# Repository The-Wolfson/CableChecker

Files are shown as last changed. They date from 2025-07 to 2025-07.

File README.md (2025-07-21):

# Cable Checker
A handheld device to check XLR3 cables faster.

## Basic Operation
This device has 3 testing modes:
- input (tests incoming signal)
- output (tests outgoing signal)
- both (tests both incoming and outgoing signals)

These are controlled by the slide switch ion the side.

To start a test, hold the rotary encoder down for 3 seconds. The test will run for 5 seconds, afterwards the LEDs will show the results and input levels.

There is also a headphone jack, the knob can be used for volume.

When in output mode, the knob is used for volume.

## BOM

| Item | Model | Qty | Price (USD) | Shipping | Link |
|-|-|-|-|-|-|
| Audio Codec | ES8388 | 1 | $2.51 | $9.34 USD | [Link](https://lcsc.com/product-detail/ADCs-DACs-Special-Purpose_Everest-semi-Everest-Semiconductor-ES8388_C365736.html) |
| Audio Transformer | HR610660 | 2 | $1.03 | '' | [Link](https://lcsc.com/product-detail/Audio-Transformers_HANRUN-Zhongshan-HanRun-Elec-HR610660_C48357.html) |
| XLR3 Male | NC3MAAH | 1 | $1.57 | '' | [Link](https://lcsc.com/product-detail/XLR-Cannon-Connectors_Neutrik-NC3MAAH_C368463.html) |
| XLR3 Female | NC3FAAH | 1 | $1.43 | '' | [Link](https://lcsc.com/product-detail/XLR-Cannon-Connectors_Neutrik-NC3FAAH_C368521.html) |
| Audio Jack | PJ-306M | 1 | $1.14 | '' | [Link](https://lcsc.com/product-detail/Audio-Connectors_HOOYA-PJ-306M_C2939172.html) |
| Rotary Encoder w/ Button | PEC11R-4220F-S0024 | 1 | $2.80  | '' | [Link](https://lcsc.com/product-detail/Rotary-Encoders_BOURNS-PEC11R-4220F-S0024_C143797.html) |
| Slide Switch (SP3T) | SK13D07VG5 | 1 | $0.66 | '' | [Link](https://lcsc.com/product-detail/Slide-Switches_SHOU-HAN-SK13D07VG5_C393948.html) |
| Microcontroller | ESP32-S3-Zero | 1 | $6.06 | Free | [Link](https://core-electronics.com.au/esp32-s3-mini-development-board-retired.html) |
| LED Bar Graph | WS2812B | 1 | $3.19 | '' | [Link](https://core-electronics.com.au/glowbit-stick-1x8.html) |
| Encoder Knob | ADA5093 | 1 | $1.17 | '' | [Link](https://core-electronics.com.au/slim-rubber-rotary-encoder-knob-11-5mm-x-14-5mm-d-shaft.html) |
| PCB (JLCPCB) | - | 5 | $2 | $16.59 AUD | [Link](https://jlcpcb.com) |
| PCB Assembly (for ES8388) | - | 2 | $15.40 | '' | [Link](https://jlcpcb.com) |
| Case (Print Legion) | - | 1 | $0 | $5 AUD | [Link](https://printlegion.hackclub.com) |

**AUD Total:** $98.46

**USD Total:** $62.35

## Background
I run sound at my school, and we have a legacy system, set up who knows how many years ago. As part of that, there are lots of XLR3 cables lying around that nobody knows if they work, or not.

The solution to my problem, a small portable device that tests if the XLR cable is functioning properly. THis exists... for around $350 AUD. 

So, when I heard about Hackclub's *Highway* YSWS, my mind immediately jumped to this.
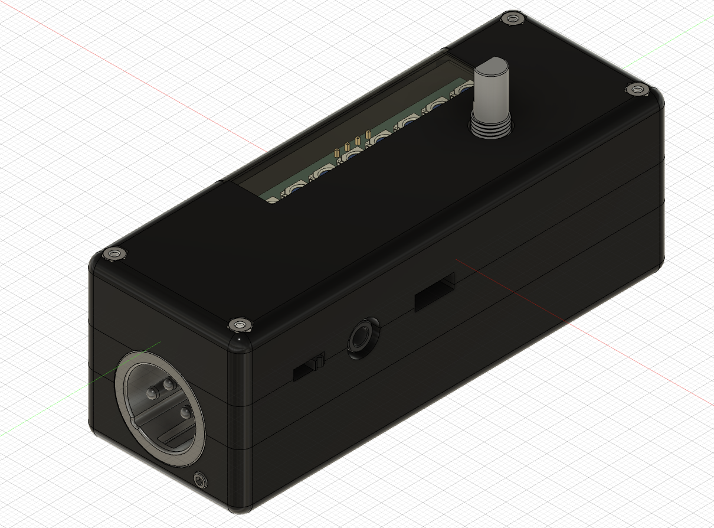
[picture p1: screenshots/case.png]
Case

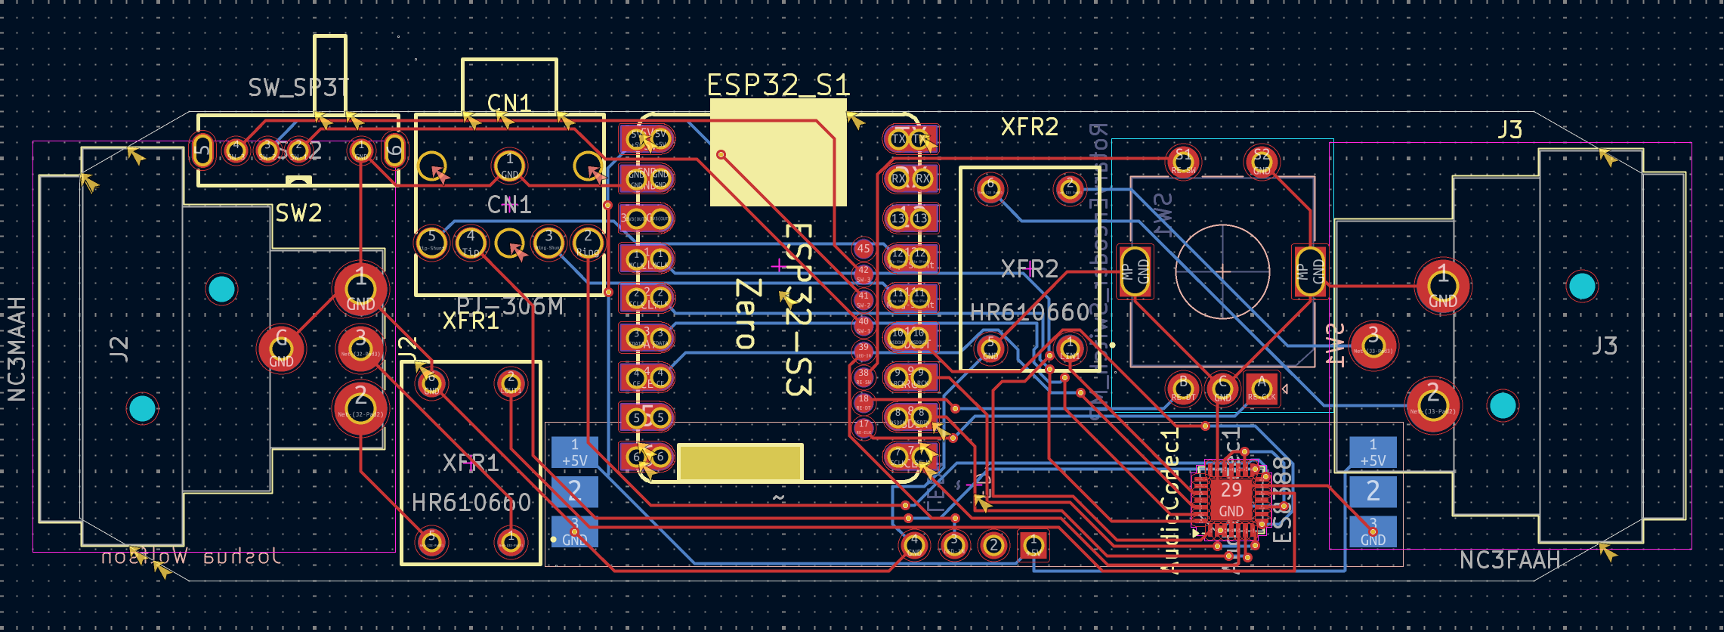
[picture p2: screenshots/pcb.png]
PCB

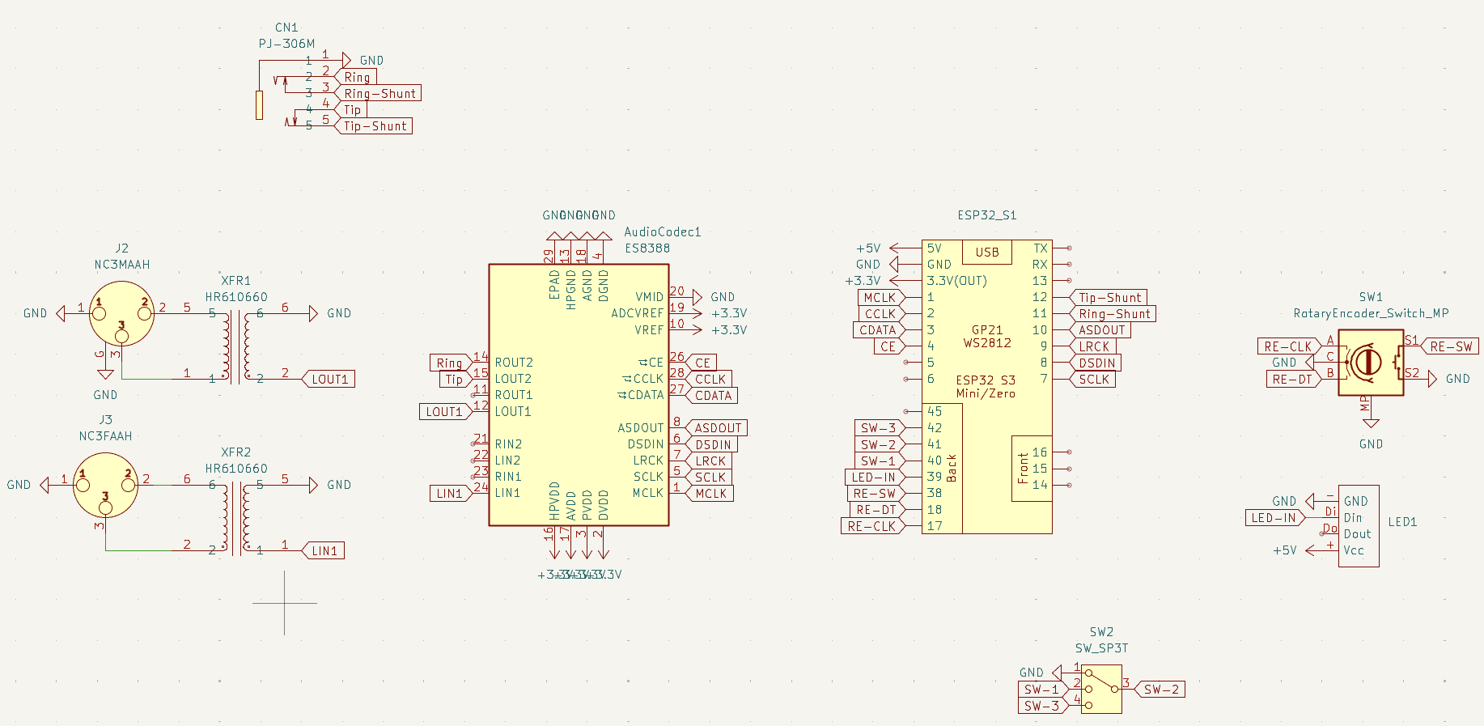
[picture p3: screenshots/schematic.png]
Schematic

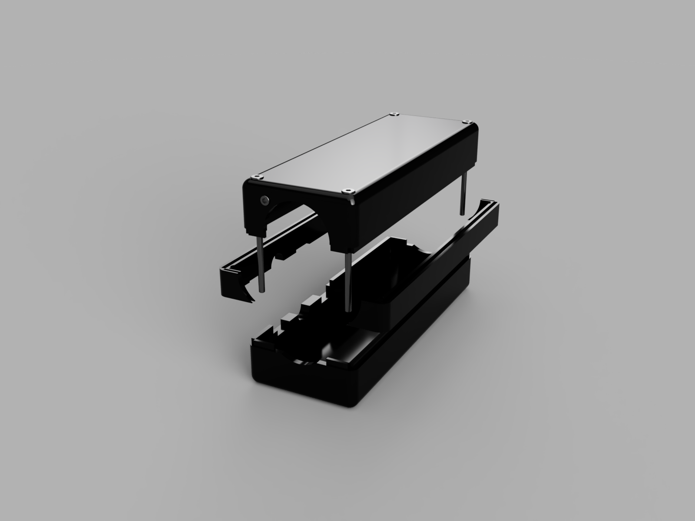
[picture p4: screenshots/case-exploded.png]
Case Assembly


## Additional Details
- I'm using a 14mmx55mmx2mm transparent acrylic sheet instead of the window print.

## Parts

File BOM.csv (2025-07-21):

Part | SKU | Model | Quantity | Price (AUD) | Price (USD) | Shipping (AUD) | Shipping (USD) | Total (AUD) | Total (USD) | Link
Audio Transformer | C48357 | HR610660 | 2 | $- | $2.51 | $- | $9.34 | $18.20 | $11.85 | https://lcsc.com/product-detail/Audio-Transformers_HANRUN-Zhongshan-HanRun-Elec-HR610660_C48357.html
Audio Codec | C365736 | ES8388 | 1 | $- | $1.03 | $- | ' | $1.58 | $1.03 | https://lcsc.com/product-detail/ADCs-DACs-Special-Purpose_Everest-semi-Everest-Semiconductor-ES8388_C365736.html
XLR3 Male | C368463 | NC3MAAH | 1 | $- | $1.57 | $- | ' | $2.41 | $1.57 | https://lcsc.com/product-detail/XLR-Cannon-Connectors_Neutrik-NC3MAAH_C368463.html
XLR3 Female | C368521 | NC3FAAH | 1 | $- | $1.43 | $- | ' | $2.20 | $1.43 | https://lcsc.com/product-detail/XLR-Cannon-Connectors_Neutrik-NC3FAAH_C368521.html
Rotary Encoder w/ Button | C143797 | PEC11R-4220F-S0024 | 1 | $- | $2.80 | $- | ' | $4.30 | $2.80 | https://lcsc.com/product-detail/Rotary-Encoders_BOURNS-PEC11R-4220F-S0024_C143797.html
Audio Jack | C2939172 | PJ-306M | 5 | $- | $1.14 | $- | ' | $1.75 | $1.14 | https://lcsc.com/product-detail/Audio-Connectors_HOOYA-PJ-306M_C2939172.html
Slide Switch (SP3T) | C393948 | SK13D07VG5 | 20 | $- | $0.66 | $- | ' | $1.01 | $0.66 | https://lcsc.com/product-detail/Slide-Switches_SHOU-HAN-SK13D07VG5_C393948.html
Microcontroller | WS-25081 | ESP32-S3-Zero | 1 | $9.30 | $- | $- | $- | $9.30 | $6.05 | https://core-electronics.com.au/esp32-s3-mini-development-board-retired.html
Encoder Knob | ADA5093 | - | 1 | $1.80 | $- | $- | $- | $1.80 | $1.17 | https://core-electronics.com.au/slim-rubber-rotary-encoder-knob-11-5mm-x-14-5mm-d-shaft.html
LED Bar Graph | CE08035 | WS2812B | 1 | $4.90 | $- | $- | ' | $4.90 | $3.19 | https://core-electronics.com.au/glowbit-stick-1x8.html
M2x38 |  |  | 4 |  |  |  |  | $- | $-
M1.6x12 |  |  | 2 |  |  |  |  | $- | $-
PCB | JLCPCB |  | 5 | $3.07 | $- | $16.59 | $- | $19.66 | $12.80 | https://jlcpcb.com
PCB Assembly (for ES8388) | JLCPCB |  | 2 | $23.67 |  |  |  | $23.67 | $15.41 | https://jlcpcb.com
Case | Printing Legion |  |  | $- | $- | $5.00 | $- | $7.68 | $3.25 | https://printlegion.hackclub.com
Total |  |  |  |  |  |  |  | $98.46 | $62.35

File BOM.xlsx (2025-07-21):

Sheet: BOM
Part | SKU | Model | Quantity | Price (AUD) | Price (USD) | Shipping (AUD) | Shipping (USD) | Total (AUD) | Total (USD) | Link
Audio Transformer | C48357 | HR610660 | 2 | $0.00 | $2.51 | $0.00 | $9.34 | $18.20 | $11.85 | https://lcsc.com/product-detail/Audio-Transformers_HANRUN-Zhongshan-HanRun-Elec-HR610660_C48357.html
Audio Codec | C365736 | ES8388 | 1 | $0.00 | $1.03 | $0.00 | ' | $1.58 | $1.03 | https://lcsc.com/product-detail/ADCs-DACs-Special-Purpose_Everest-semi-Everest-Semiconductor-ES8388_C365736.html
XLR3 Male | C368463 | NC3MAAH | 1 | $0.00 | $1.57 | $0.00 | ' | $2.41 | $1.57 | https://lcsc.com/product-detail/XLR-Cannon-Connectors_Neutrik-NC3MAAH_C368463.html
XLR3 Female | C368521 | NC3FAAH | 1 | $0.00 | $1.43 | $0.00 | ' | $2.20 | $1.43 | https://lcsc.com/product-detail/XLR-Cannon-Connectors_Neutrik-NC3FAAH_C368521.html
Rotary Encoder w/ Button | C143797 | PEC11R-4220F-S0024 | 1 | $0.00 | $2.80 | $0.00 | ' | $4.30 | $2.80 | https://lcsc.com/product-detail/Rotary-Encoders_BOURNS-PEC11R-4220F-S0024_C143797.html
Audio Jack | C2939172 | PJ-306M | 5 | $0.00 | $1.14 | $0.00 | ' | $1.75 | $1.14 | https://lcsc.com/product-detail/Audio-Connectors_HOOYA-PJ-306M_C2939172.html
Slide Switch (SP3T) | C393948 | SK13D07VG5 | 20 | $0.00 | $0.66 | $0.00 | ' | $1.01 | $0.66 | https://lcsc.com/product-detail/Slide-Switches_SHOU-HAN-SK13D07VG5_C393948.html
Microcontroller | WS-25081 | ESP32-S3-Zero | 1 | $9.30 | $0.00 | $0.00 | $0.00 | $9.30 | $6.05 | https://core-electronics.com.au/esp32-s3-mini-development-board-retired.html
Encoder Knob | ADA5093 | - | 1 | $1.80 | $0.00 | $0.00 | $0.00 | $1.80 | $1.17 | https://core-electronics.com.au/slim-rubber-rotary-encoder-knob-11-5mm-x-14-5mm-d-shaft.html
LED Bar Graph | CE08035 | WS2812B | 1 | $4.90 | $0.00 | $0.00 | ' | $4.90 | $3.19 | https://core-electronics.com.au/glowbit-stick-1x8.html
M2x38 |  |  | 4 |  |  |  |  | $0.00 | $0.00
M1.6x12 |  |  | 2 |  |  |  |  | $0.00 | $0.00
PCB | JLCPCB |  | 5 | $3.07 | $0.00 | $16.59 | $0.00 | $19.66 | $12.80 | https://jlcpcb.com
PCB Assembly (for ES8388) | JLCPCB |  | 2 | $23.67 |  |  |  | $23.67 | $15.41 | https://jlcpcb.com
Case | Printing Legion |  |  | $0.00 | $0.00 | $5.00 | $0.00 | $7.68 | $3.25 | https://printlegion.hackclub.com
Total |  |  |  |  |  |  |  | $98.46 | $62.35

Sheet: Exchange
Currency Pair | Price | Last trade time
#VALUE! | $1.54 | 2025-07-21 09:34
#VALUE! | $0.65 | 2025-07-21 09:34

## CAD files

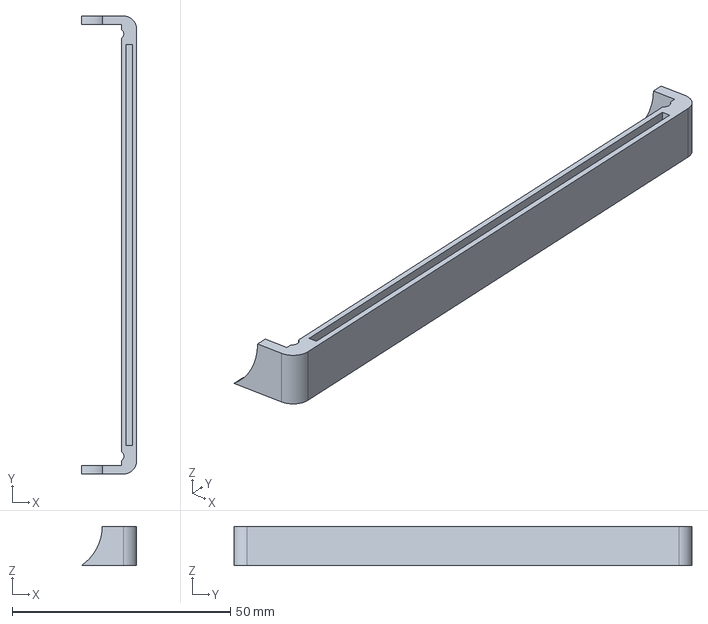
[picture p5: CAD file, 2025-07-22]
production/case/middle (1).step
12.7 x 105.0 x 9.00 mm

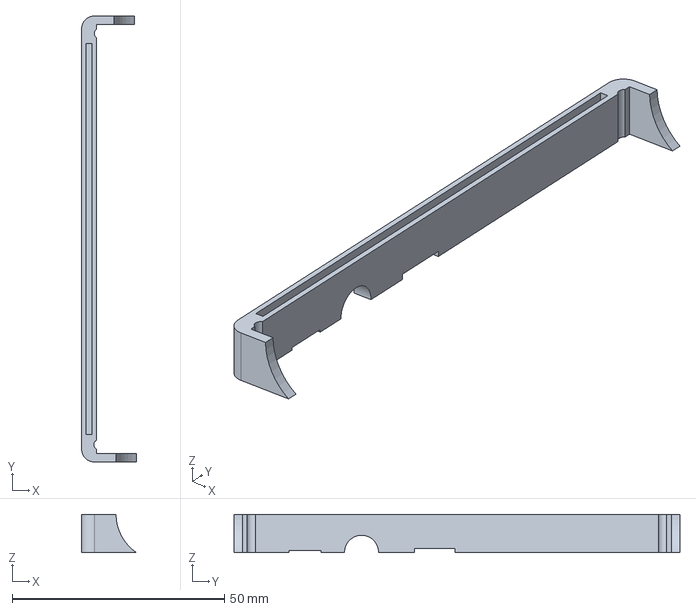
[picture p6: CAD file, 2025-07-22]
production/case/middle (2).step
12.9 x 105.0 x 9.00 mm

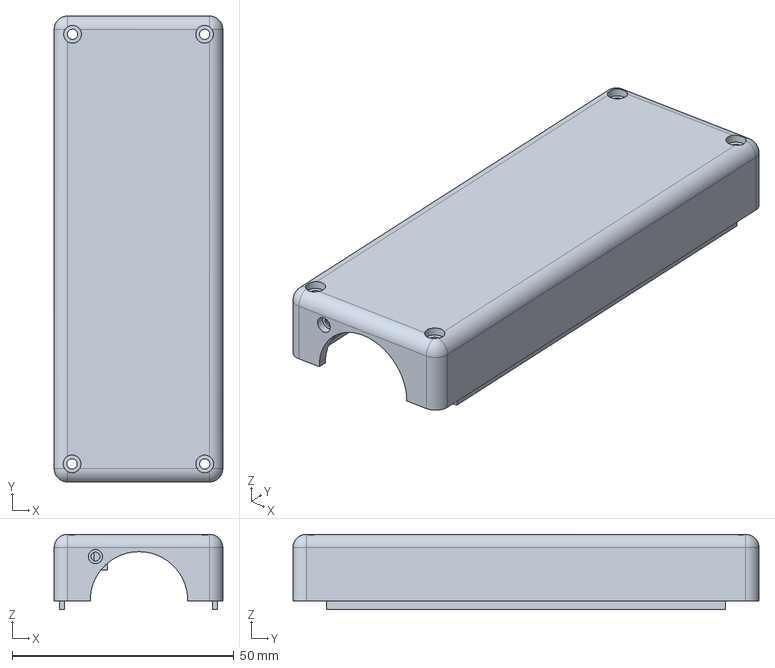
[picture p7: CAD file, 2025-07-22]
production/case/top.step
38.0 x 105.0 x 17.0 mm

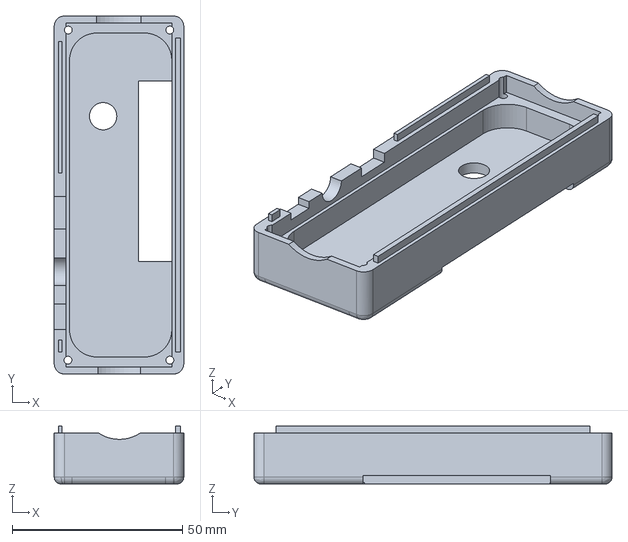
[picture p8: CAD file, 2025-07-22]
production/case/bottom.step
38.0 x 105.0 x 17.0 mm

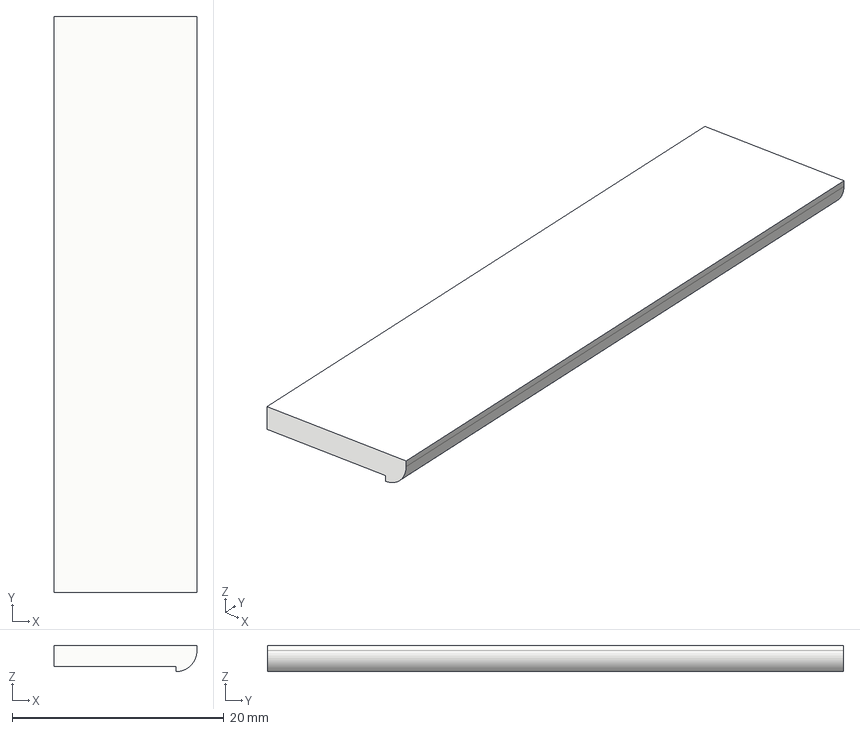
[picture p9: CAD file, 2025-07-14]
production/case/window.step
13.5 x 54.4 x 2.50 mm

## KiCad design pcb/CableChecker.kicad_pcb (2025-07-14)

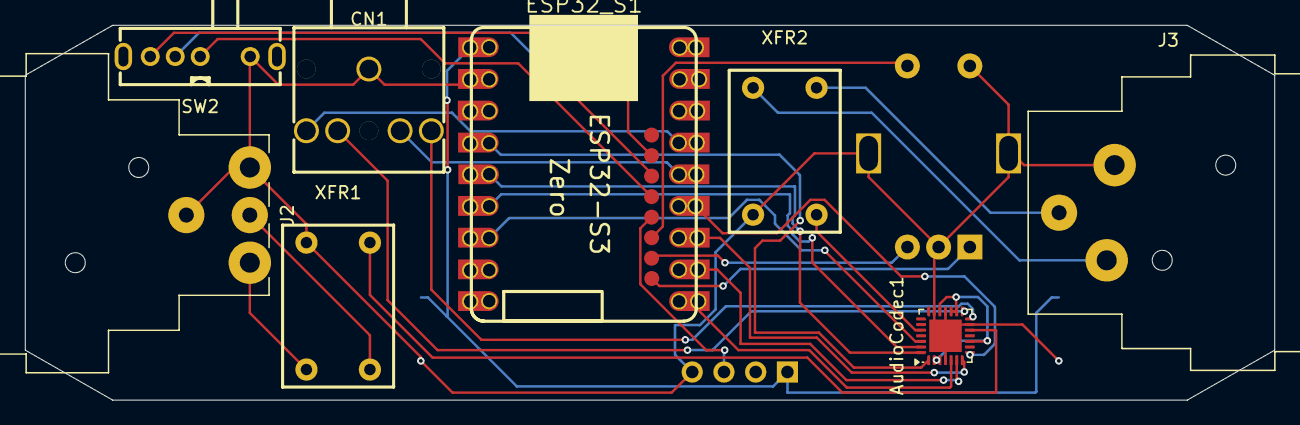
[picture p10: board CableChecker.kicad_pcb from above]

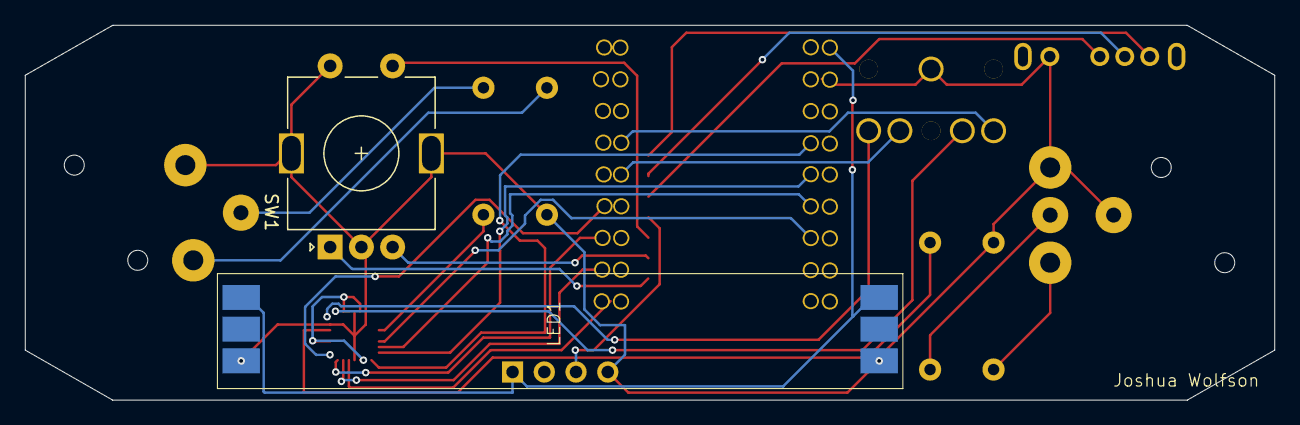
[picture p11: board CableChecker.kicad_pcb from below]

Board: 2 copper layers, 100.0 x 30.0 mm, 10 parts (2 on the bottom side), 28 nets.

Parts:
AudioCodec1: ES8388; QFN-28-1EP_4x4mm_P0.45mm_EP2.6x2.6mm
CN1: PJ-306M; AUDIO-TH_HOOYA_PJ-306M
ESP32_S1: ESP32-S3-ZERO
J2: NC3MAAH; Jack_XLR_Neutrik_NC3MAAH_Horizontal
J3: NC3FAAH; Jack_XLR_Neutrik_NC3FAAH_Horizontal
LED1: GlowbitL_LED_Strip_1x8
SW1: RotaryEncoder_Switch_MP; RotaryEncoder_Alps_EC11E-Switch_Vertical_H20mm
SW2: SW_SP3T; SW-TH_SK13D07VG5
XFR1, XFR2: HR610660; PWRM-TH_HR610660

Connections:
+3.3V: AudioCodec1.2 (DVDD), AudioCodec1.3 (PVDD), AudioCodec1.10 (VREF), AudioCodec1.16 (HPVDD), AudioCodec1.17 (AVDD), AudioCodec1.19 (ADCVREF)
+5V: ESP32_S1.5V, LED1.1
ASDOUT: AudioCodec1.8 (ASDOUT), ESP32_S1.10
CCLK: AudioCodec1.28 (CCLK), ESP32_S1.2
CDATA: AudioCodec1.27 (CDATA), ESP32_S1.3
CE: AudioCodec1.26 (CE), ESP32_S1.4
DSDIN: AudioCodec1.6 (DSDIN), ESP32_S1.8
GND: AudioCodec1.4 (DGND), AudioCodec1.13 (HPGND), AudioCodec1.18 (AGND), AudioCodec1.20 (VMID), AudioCodec1.29 (EPAD), CN1.1, ESP32_S1.GND, J2.1, J2.G, J3.1, LED1.3, LED1.4, SW1.C, SW1.MP, SW1.S2, SW2.1, XFR1.6, XFR2.5
LED-IN: ESP32_S1.39, LED1.3
LIN1: AudioCodec1.24 (LIN1), XFR2.1
LOUT1: AudioCodec1.12 (LOUT1), XFR1.2
LRCK: AudioCodec1.7 (LRCK), ESP32_S1.9
MCLK: AudioCodec1.1 (MCLK), ESP32_S1.1
unnamed: J2.2, XFR1.5
unnamed: J2.3, XFR1.1
unnamed: J3.2, XFR2.6
unnamed: J3.3, XFR2.2
RE-CLK: ESP32_S1.17, SW1.A
RE-DT: ESP32_S1.18, SW1.B
RE-SW: ESP32_S1.38, SW1.S1
Ring: AudioCodec1.14 (ROUT2), CN1.2
Ring-Shunt: CN1.3, ESP32_S1.11
SCLK: AudioCodec1.5 (SCLK), ESP32_S1.7
SW-1: ESP32_S1.40, SW2.2
SW-2: ESP32_S1.41, SW2.3
SW-3: ESP32_S1.42, SW2.4
Tip: AudioCodec1.15 (LOUT2), CN1.4
Tip-Shunt: CN1.5, ESP32_S1.12

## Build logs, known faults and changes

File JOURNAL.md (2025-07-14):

---
title: "CableChecker"
author: "Joshua Wolfson"
description: "A portable tool for techies to check XLR cables."
created_at: "2025-06-22"
---

**Total Time:** 35 hours

# 23rd June: Initial conception and part sourcing.

Initial conception of the idea: an easy way for theatre techs to check whether xlr cables work.

After a bit of brainstorming, heres the BOM I arrived at:

| Item | Model | Qty | Price | Shipping | Link |
|---|---|-----|---|---|---|
| Audio Codec | ES8388 | 1 | $26.99 | $12.40 | [ES8388 Module](https://pcbartists.com/product/es8388-module/) |
| Audio Transformer | ED8 | 2 | $2.92 | $2.50 | [ED8 Transformer](https://www.aliexpress.com/i/1005002450695711.html) |
| XLR3 Male | NC3MAAV | 1 | $1.74 | $3.98 | |
| XLR3 Female | NC3FAAV | 1 | $1.74 | | |
| Microcontroller | ESP32-S3 | 1 | $9.30 | Free | [ESP32-S3 Mini](https://core-electronics.com.au/esp32-s3-mini-development-board-retired.html) |
| Rotary Encoder w/ Button | EC11 | 1 | $5.25 | Free | [EC11 Encoder Module](https://core-electronics.com.au/ec11-rotary-encoder-module.html) |
| LED Bar Graph | HDSP-4836 | 1 | $8.50 | Free | [12-LED Bargraph](https://core-electronics.com.au/bi-color-red-green-12-led-bargraph-pack-of-2.html) |

**Total:** $56.44  
**Total (inc. Shipping):** $75.32

Yes, I know the ES8388 is expensive, I'm going to do some more digging over the next few days for some alternatives.

Anyway, this is my first time doing anything to do with pcb's and the like, I normally code my way out of problems. So we'll see how it goes.

With that being said, I'm onto wiring and modelling tomorrow.

Thanks for following along,

Josh

**Total time spent: 2h**

# 25th June: Finalising BOM and starting Wiring/Modelling

This is my updated parts list:

| Part | SKU | Model | Quantity | Price | Shipping | Link |
|---|---|---|---|---|---|---|
| Audio Module | PCBA2103  | ES8388 | 1 | $26.99  | $12.40 | [Link](https://pcbartists.com/product/es8388-module/) |
| Audio Transformer | | ED8 | 2 | $5.84 | $2.50 | [Link](https://www.aliexpress.com/i/1005002450695711.html) |
| XLR3 Male | NC3MAAV | XLR3 | 1 | $1.74 | $3.98 | [Link](https://www.aliexpress.com/item/1005003251181647.html) |
| XLR3 Female | NC3FAAV | XLR3 | 1 | $1.74 | '' | [Link](https://www.aliexpress.com/item/1005003251181647.html) |
| Microcontroller | WS-25081  | ESP32-S3 | 1 | $9.30 | Free | [Link](https://core-electronics.com.au/esp32-s3-mini-development-board-retired.html)  |
| Rotary Encoder w/ Button | ADA377 | PEC11 | 1 | $9.95 | '' | [Link](https://core-electronics.com.au/rotary-encoder-extras.html) |
| LED Bar Graph | ADA1719 | KWL-R1230XDUGB | 2  | $8.50 | '' | [Link](https://core-electronics.com.au/bi-color-red-green-12-led-bargraph-pack-of-2.html) |

**Total:** $64.06 (AUD)
**Total (inc. Shipping):** $82.94 (AUD)

I found a rotary encoder with a lower profile. I think, unfortunately, that I'm going to have to shell out for the PCB artists ES8388.

On another note, I've started wiring and modelling the body using KiCad and Fusion360.

Thanks for following along,

Josh

**Total time spent: 5h**

# 9th July: Schematic editing and firmware
Ok a lot to cover in this one, I've been busy for the last week, and so have been unable to get around to this project. But the day til highway ends draws near, so this project needs an update.
I decided to make a start on the firmware, the majority if my time was spent figuring out how to use Espressif's IDF with CLion, and the rest on working out how to interface with the ES8388 using espressif/esp_codec_dev, a very poorly documented library. Despite all this I have made a definite start, with more to follow in the morning.
Most of the parts I'm using don't have KiCad symbols or footprints available, however, thanks to the [symbol design guide](https://highway.hackclub.com/guides/symbol-design), I have been able to push through and finally lay down a rough plan for wiring (we'll see how I go).

KiCad Schematic

**Total time spent: 7h**

# 13th July: Finished hardware.
I'm probably not keeping this thing as updated as i should... After wrestling with ESP-IDF and ESP-ADF for days on end, I decided to switch tracks and finish the hardware. And along the way i made some pretty drastic changes; the BOM has changed, the materials have changed, the design has changed. But it's for the best as I'm now 96% done with the hardware, and the bones of the firmware have been laid out. I still need to figure out how to attach the 4 parts of my case together (heat insets? snap joints?).
With that (short) update,
I'm for bed.
Happy coding :}

PCB
3D Render

**Total time spent: 15h**

# 14th July: I'm done! (theoretically)
I've finished the case, the PCB, and the firmware. While the firmware isn't polished, it's enough for an MVP (and it will be a lot easier to see what's working when I have it in my hands). One thing that I will have to check with the Hackclub crew, is am I allowed to pay for JLCPCB to put the ES8388 chip on the board, they offer it as a service and I, as a beginner, am not confident in my prowess with a soldering iron.

I am using 4 M2 bolts to hold the case together (with the help of some superglue), and 2 M1.6 bolts, these shouldn't be hard to source as there is a hardware shop down the road.

I have written a README.MD, and exported my pcb and case. I'm off to submit and hopefully the next time I'm writing in this, I'll have a PCB and some components to assemble.
It's been an interesting journey,
Happy Coding ;}

**Total time spent: 5h**

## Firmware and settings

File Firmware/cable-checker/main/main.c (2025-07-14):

#include <sys/param.h>

#include "audio_pipeline.h"
#include "board.h"
#include "led_strip.h"
#include "button_gpio.h"
#include "esp_log.h"
#include "gpios.h"
#include "i2s_stream.h"
#include "iot_button.h"
#include "led_strip_interface.h"
#include "raw_stream.h"
#include "driver/pulse_cnt.h"
#include "wav_decoder.h"
#include "audio/short_test.h"
#include "es8388.h"

typedef enum {
    MODE_PLAY,
    MODE_RECORD,
    MODE_BOTH
} Mode;

//MARK: Global variables
Mode current_mode;
static bool headphone_inserted = false;
led_strip_handle_t led_strip;

//MARK: Init function
button_handle_t init_button(const int gpio, const int active_level) {
    const button_config_t btn_cfg = {.long_press_time = 3000};
    const button_gpio_config_t btn_gpio_cfg = {
        .gpio_num = gpio,
        .active_level = active_level,
    };
    button_handle_t button = NULL;
    ESP_ERROR_CHECK(iot_button_new_gpio_device(&btn_cfg, &btn_gpio_cfg, &button));
    return button;
}

//Doing functions
void flash_leds() {
    for (int i = 1; i < LED_COUNT; i++) {
        led_strip_set_pixel(led_strip, i, 255, 255, 255); // RGB = white
    }
    led_strip_refresh(led_strip);

    vTaskDelay(pdMS_TO_TICKS(500));

    led_strip_clear(led_strip);
}

bool compare_audio_buffers(char *buf1, char *buf2, size_t len, int threshold) {
    int diff_count = 0;
    for (int i = 0; i < len; i++) {
        if (abs(buf1[i] - buf2[i]) > threshold) {
            diff_count++;
        }
    }
    return diff_count < (len / 10); // Arbitrary threshold
}

void play_test() {
    audio_board_handle_t board_handle = audio_board_init();
    audio_hal_ctrl_codec(board_handle->audio_hal, AUDIO_HAL_CODEC_MODE_BOTH, AUDIO_HAL_CTRL_START);

    es_adc_input_t input = ADC_INPUT_MIC1;
    es8388_config_adc_input(input);
    es_dac_output_t output = DAC_OUTPUT_LOUT1;
    es8388_config_dac_output(output);

    // ----- Playback pipeline -----
    audio_pipeline_cfg_t pipeline_cfg = DEFAULT_AUDIO_PIPELINE_CONFIG();
    audio_pipeline_handle_t pipeline_play = audio_pipeline_init(&pipeline_cfg);
    audio_pipeline_handle_t pipeline_record = audio_pipeline_init(&pipeline_cfg);

    // raw stream from memory
    raw_stream_cfg_t raw_cfg_mem = RAW_STREAM_CFG_DEFAULT();
    raw_cfg_mem.type = AUDIO_STREAM_READER;
    audio_element_handle_t raw_reader_mem = raw_stream_init(&raw_cfg_mem);

    // WAV decoder
    audio_element_handle_t wav_decoder = wav_decoder_init(NULL);

    // I2S writer to ES8388 DAC
    i2s_stream_cfg_t i2s_cfg = I2S_STREAM_CFG_DEFAULT();
    i2s_cfg.type = AUDIO_STREAM_WRITER;
    audio_element_handle_t i2s_writer = i2s_stream_init(&i2s_cfg);

    audio_pipeline_register(pipeline_play, raw_reader_mem, "raw_mem");
    audio_pipeline_register(pipeline_play, wav_decoder, "wav");
    audio_pipeline_register(pipeline_play, i2s_writer, "i2s_writer");
    audio_pipeline_link(pipeline_play, (const char *[]){"raw_mem", "wav", "i2s_writer"}, 3);

    // ----- Record pipeline -----
    raw_stream_cfg_t raw_cfg_in = RAW_STREAM_CFG_DEFAULT();
    raw_cfg_in.type = AUDIO_STREAM_READER;
    audio_element_handle_t raw_reader_in = raw_stream_init(&raw_cfg_in);

    i2s_cfg.type = AUDIO_STREAM_READER;
    audio_element_handle_t i2s_reader = i2s_stream_init(&i2s_cfg);

    audio_pipeline_register(pipeline_record, i2s_reader, "i2s_reader");
    audio_pipeline_register(pipeline_record, raw_reader_in, "raw_in");
    audio_pipeline_link(pipeline_record, (const char *[]){"i2s_reader", "raw_in"}, 2);

    // Start both pipelines
    audio_pipeline_run(pipeline_play);
    audio_pipeline_run(pipeline_record);

    // Feed memory buffer to playback pipeline manually
    int sent = 0;
    char record_buf[short_test_wav_len];

    while (sent < short_test_wav_len) {
        int chunk = MIN(short_test_wav_len, short_test_wav_len - sent);
        raw_stream_write(raw_reader_mem, &short_test_wav[sent], chunk);
        sent += chunk;

        int rec_bytes = raw_stream_read(raw_reader_in, record_buf, chunk);
        if (rec_bytes > 0) {
            compare_audio_buffers(&short_test_wav[sent - chunk], record_buf, rec_bytes, 5);
        }

        vTaskDelay(pdMS_TO_TICKS(100));
    }

    // Cleanup
    audio_pipeline_stop(pipeline_play);
    audio_pipeline_wait_for_stop(pipeline_play);
    audio_pipeline_terminate(pipeline_play);

    audio_pipeline_stop(pipeline_record);
    audio_pipeline_wait_for_stop(pipeline_record);
    audio_pipeline_terminate(pipeline_record);

    audio_pipeline_unregister(pipeline_play, raw_reader_mem);
    audio_pipeline_unregister(pipeline_play, wav_decoder);
    audio_pipeline_unregister(pipeline_play, i2s_writer);
    audio_pipeline_unregister(pipeline_record, i2s_reader);
    audio_pipeline_unregister(pipeline_record, raw_reader_in);

    audio_element_deinit(raw_reader_mem);
    audio_element_deinit(wav_decoder);
    audio_element_deinit(i2s_writer);
    audio_element_deinit(i2s_reader);
    audio_element_deinit(raw_reader_in);

    audio_pipeline_deinit(pipeline_play);
    audio_pipeline_deinit(pipeline_record);
}

void record_test() {

}


//MARK: Callback functions
void select_mode_cb(void *arg, void *usr_data) {
    Mode new_mode = *(Mode *) usr_data;
    current_mode = new_mode;

    switch (current_mode) {
        case MODE_PLAY:
            led_strip_set_pixel(led_strip, MODE_LED_INDEX, 255, 0, 0);
            break;
        case MODE_RECORD:
            led_strip_set_pixel(led_strip, MODE_LED_INDEX, 0, 255, 0);
            break;
        default:
            led_strip_set_pixel(led_strip, MODE_LED_INDEX, 0, 0, 255);
            break;
    }
    led_strip_refresh(led_strip);
}

void headphone_insert_cb(void *arg, void *usr_data) {
    ESP_LOGI("Headphone", "Inserted");
    headphone_inserted = true;
    flash_leds();
}

void headphone_remove_cb(void *arg, void *usr_data) {
    ESP_LOGI("Headphone", "Removed");
    headphone_inserted = false;
    flash_leds();
}

void encoder_hold_cb(void *arg, void *usr_data) {
    ESP_LOGI("Encoder", "Hold");
    // Handle encoder hold event
    flash_leds();
    play_test();
}

void encoder_click_cb(void *arg, void *usr_data) {
    ESP_LOGI("Encoder", "Clicked");
    // Handle encoder click event
    flash_leds();
}

bool encoder_turned_cb(pcnt_unit_handle_t unit, const pcnt_watch_event_data_t *edata, void *user_ctx) {
    ESP_LOGI("Encoder", "Turned");
    // Handle encoder click event
    flash_leds();
    return true;
}

//Setup functions
void setup_led() {
    /// LED strip common configuration
    led_strip_config_t strip_config = {
        .strip_gpio_num = LED_DIN, // The GPIO that connected to the LED strip's data line
        .max_leds = LED_COUNT, // The number of LEDs in the strip,
        .led_model = LED_MODEL_WS2812, // LED strip model, it determines the bit timing
        .color_component_format = LED_STRIP_COLOR_COMPONENT_FMT_GRB, // The color component format is G-R-B
        .flags = {
            .invert_out = false, // don't invert the output signal
        }
    };

    /// RMT backend specific configuration
    led_strip_rmt_config_t rmt_config = {
        .clk_src = RMT_CLK_SRC_DEFAULT, // different clock source can lead to different power consumption
        .resolution_hz = 10 * 1000 * 1000, // RMT counter clock frequency: 10MHz
        .mem_block_symbols = 64, // the memory size of each RMT channel, in words (4 bytes)
        .flags = {
            .with_dma = false, // DMA feature is available on chips like ESP32-S3/P4
        }
    };

    /// Create the LED strip object
    ESP_ERROR_CHECK(led_strip_new_rmt_device(&strip_config, &rmt_config, &led_strip));
}

void setup_SP3T() {
    button_handle_t switch_a = init_button(SP3T_A, 0);
    static Mode mode_play = MODE_PLAY;
    iot_button_register_cb(switch_a, BUTTON_ACTIVE, NULL, select_mode_cb, &mode_play);

    button_handle_t switch_b = init_button(SP3T_B, 0);
    static Mode mode_both = MODE_BOTH;
    iot_button_register_cb(switch_b, BUTTON_ACTIVE, NULL, select_mode_cb, &mode_both);

    button_handle_t switch_c = init_button(SP3T_C, 0);
    static Mode mode_record = MODE_RECORD;
    iot_button_register_cb(switch_c, BUTTON_ACTIVE, NULL, select_mode_cb, &mode_record);
}

void setup_ring_shunt() {
    button_handle_t ring_shunt = init_button(RSH, 1);
    iot_button_register_cb(ring_shunt, BUTTON_PRESS_DOWN, NULL, headphone_insert_cb, NULL);
    iot_button_register_cb(ring_shunt, BUTTON_PRESS_UP, NULL, headphone_remove_cb, NULL);
}

void setup_encoder_button() {
    button_handle_t encoder_button = init_button(ROTARY_SW, 0);
    iot_button_register_cb(encoder_button, BUTTON_LONG_PRESS_START, NULL, encoder_hold_cb, NULL);
    iot_button_register_cb(encoder_button, BUTTON_SINGLE_CLICK, NULL, encoder_click_cb, NULL);
}

void setup_rotary_encoder() {
    pcnt_unit_config_t unit_config = {
        .high_limit = 100,
        .low_limit = (-100),
    };
    pcnt_unit_handle_t pcnt_unit = NULL;
    ESP_ERROR_CHECK(pcnt_new_unit(&unit_config, &pcnt_unit));

    pcnt_chan_config_t chan_a_config = {
        .edge_gpio_num = ROTARY_CLK,
        .level_gpio_num = ROTARY_DT,
    };
    pcnt_channel_handle_t pcnt_chan_a = NULL;
    ESP_ERROR_CHECK(pcnt_new_channel(pcnt_unit, &chan_a_config, &pcnt_chan_a));

    pcnt_chan_config_t chan_b_config = {
        .edge_gpio_num = ROTARY_DT,
        .level_gpio_num = ROTARY_CLK,
    };
    pcnt_channel_handle_t pcnt_chan_b = NULL;
    ESP_ERROR_CHECK(pcnt_new_channel(pcnt_unit, &chan_b_config, &pcnt_chan_b));

    pcnt_event_callbacks_t event_callbacks = {
        .on_reach = encoder_turned_cb,
    };
    pcnt_unit_register_event_callbacks(pcnt_unit, &event_callbacks, NULL);
}

//MARK: Main
void app_main(void) {
    setup_led();
    setup_ring_shunt();
    setup_encoder_button();
    setup_rotary_encoder();
    setup_SP3T();
}

/*
Led show output
Reserve one led for mode

Input gain is managed by software

When headphones, use half led for output, half for Jack -> click to switch (half that changing flashes)

When headphones, start with volume low
In
Hold for 3 secs to start test
Display input
Flash green/yellow/red
Run for 5
Out
Hold for 3 secs to start test
Generate sine wave/white noise
Start with low volume, let user use encoder to turn up.
Hold for 3 secs to end
Both
Hold for 3 secs to start test
Run for 5
 */

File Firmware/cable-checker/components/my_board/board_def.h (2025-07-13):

#ifndef _AUDIO_BOARD_DEFINITION_H_
#define _AUDIO_BOARD_DEFINITION_H_

// ES8388
///I2C
#define CCLK                2 //SCL
#define CDATA               3 //SDA
#define CE                  4
///I2S
#define MCLK                1
#define ASDOUT              10 //DOUT
#define LRCK                9 //WS
#define DSDIN               8 //DIN
#define SCLK                7 //BCLK

#define BUTTON_VOLUP_ID           -1     /* You need to define the GPIO pins of your board */
#define BUTTON_VOLDOWN_ID         -1     /* You need to define the GPIO pins of your board */
#define BUTTON_MUTE_ID            -1     /* You need to define the GPIO pins of your board */
#define BUTTON_SET_ID             -1     /* You need to define the GPIO pins of your board */
#define BUTTON_MODE_ID            -1     /* You need to define the GPIO pins of your board */
#define BUTTON_PLAY_ID            -1     /* You need to define the GPIO pins of your board */
#define PA_ENABLE_GPIO            -1     /* You need to define the GPIO pins of your board */
#define ADC_DETECT_GPIO           -1     /* You need to define the GPIO pins of your board */
#define BATTERY_DETECT_GPIO       -1     /* You need to define the GPIO pins of your board */
#define SDCARD_INTR_GPIO          -1     /* You need to define the GPIO pins of your board */

#define SDCARD_OPEN_FILE_NUM_MAX  -1

#define BOARD_PA_GAIN             (10) /* Power amplifier gain defined by board (dB) */

#define SDCARD_PWR_CTRL             -1
#define ESP_SD_PIN_CLK              -1
#define ESP_SD_PIN_CMD              -1
#define ESP_SD_PIN_D0               -1
#define ESP_SD_PIN_D1               -1
#define ESP_SD_PIN_D2               -1
#define ESP_SD_PIN_D3               -1
#define ESP_SD_PIN_D4               -1
#define ESP_SD_PIN_D5               -1
#define ESP_SD_PIN_D6               -1
#define ESP_SD_PIN_D7               -1
#define ESP_SD_PIN_CD               -1
#define ESP_SD_PIN_WP               -1

extern audio_hal_func_t AUDIO_NEW_CODEC_DEFAULT_HANDLE;

#define AUDIO_CODEC_DEFAULT_CONFIG(){                   \
        .adc_input  = AUDIO_HAL_ADC_INPUT_LINE1,        \
        .dac_output = AUDIO_HAL_DAC_OUTPUT_ALL,         \
        .codec_mode = AUDIO_HAL_CODEC_MODE_BOTH,        \
        .i2s_iface = {                                  \
            .mode = AUDIO_HAL_MODE_SLAVE,               \
            .fmt = AUDIO_HAL_I2S_NORMAL,                \
            .samples = AUDIO_HAL_48K_SAMPLES,           \
            .bits = AUDIO_HAL_BIT_LENGTH_16BITS,        \
        },                                              \
};

#define INPUT_KEY_NUM     0             /* You need to define the number of input buttons on your board */

#define INPUT_KEY_DEFAULT_INFO() {}

#endif

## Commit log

2025-06-23 Added BOM
    [BOM.csv]
2025-06-25 BOM Update
    [BOM.csv]
2025-07-09 started firmware
    [BOM.csv]
2025-07-11 added adf
    [BOM.xlsx, CableChecker.kicad_pcb, CableChecker.kicad_sch]
2025-07-13 hardware mostly done
    [BOM.xlsx, CableChecker.kicad_pcb, CableChecker.kicad_sch]
2025-07-14 finished hardware
    [BOM.csv, BOM.xlsx, CableChecker.kicad_pcb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]
2025-07-14 updated window
    [bottom.step, window.step]
2025-07-14 fixed issue with total price
    [BOM.csv, BOM.xlsx]
2025-07-21 updated BOM
    [BOM.csv, BOM.xlsx]
2025-07-21 added encoder knob
    [BOM.csv, BOM.xlsx]
2025-07-22 fixed tolerances
    [bottom.step, middle (1).step, middle (2).step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]
2025-07-26 added drill files
